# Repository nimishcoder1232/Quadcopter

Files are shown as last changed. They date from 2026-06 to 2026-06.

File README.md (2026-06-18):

# DIY-Quad-Copter
I want to make a drone that is completely autonomous, with my own flight computer. I will not use any drone control software; rather, I will make it all. The code from scratch, to learn as much as I can.

For the outpost submission, I will request S teir, rather than A teir. My reasons are following:

1. Custom Flight Control Software

The drone's flight software is entirely custom and has been developed from scratch by me. Unlike drones that rely on commercial off-the-shelf (COTS) flight control software such as Betaflight or similar systems, this project requires the development of a complete flight control stack, including sensor fusion, state estimation, and stabilization algorithms.

Developing this software has required extensive research into control systems, quaternion-based orientation estimation, complementary filters, and drone dynamics. Additionally, I anticipate multiple iterations and redesigns of the software before achieving reliable flight performance, making this a highly ambitious component of the project.

2. GPS-Based Autonomous Navigation

This drone is designed to support GPS navigation capabilities. The current codebase already contains foundational GPS-related functionality, and future development will include point-to-point autonomous navigation.

Implementing autonomous navigation significantly increases the complexity of the system, as it requires integration of GPS data with the flight controller, position estimation, waypoint tracking, and autonomous control logic.

3. Custom Ground Control System

In the PCB folder, you can see that I designed my own drone control board, rather than a COTS solution. 

CAD Screenshot: 


PCB Schematic: 


PCB Routing: 


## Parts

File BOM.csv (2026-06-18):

Item Name | Qty | Price (total) (USD) | Item link | Notes
Brushless motors and ESC | 1 | $53.00 | https://www.amazon.com/gp/product/B0BW5H7Y8Q/ref | This is an example part! Add things to note here.
Batteries | 1 | $53.00 | https://www.amazon.com/gp/product/B09CTSD386/ref
Cost to hackclub | 106$ | (Dont forget tax :D)
Stuff I will provide myself:
GNSS GPS | 1 |  | https://www.amazon.com/hiBCTR-GY-NEO6MV2-Controller-Ceramic-Antenna/dp/B0FWC1J7J4/ref
Fillament | 1 |  | (Varrious Sources)
ESP 32 s3 | 1 |  | https://www.amazon.com/Development-ESP32-S3-DevKit-Bluetooth-Internet-ESP32-S3-1-N16R8/dp/B0GVQJ5TST/ref
BMI270 | 1 |  | https://www.sparkfun.com/sparkfun-6dof-imu-breakout-bmi270-qwiic.html
LM317 | 1 |  | https://www.amazon.com/ALLECIN-LM317T-Voltage-Regulator-Adjustable/dp/B0CBLN2X7H/ref
Resistors | 1 |  | https://www.amazon.com/ONJYHK-100Values-Resistor-Resistors-Assortment/dp/B0GJYDKNPC/ref=
Capasitors | 1 |  | https://www.amazon.com/ALLECIN-Electrolytic-Capacitor-Assortment-Kit/dp/B0C1VBXCQM/ref

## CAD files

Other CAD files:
CAD/dronefinalcad.step

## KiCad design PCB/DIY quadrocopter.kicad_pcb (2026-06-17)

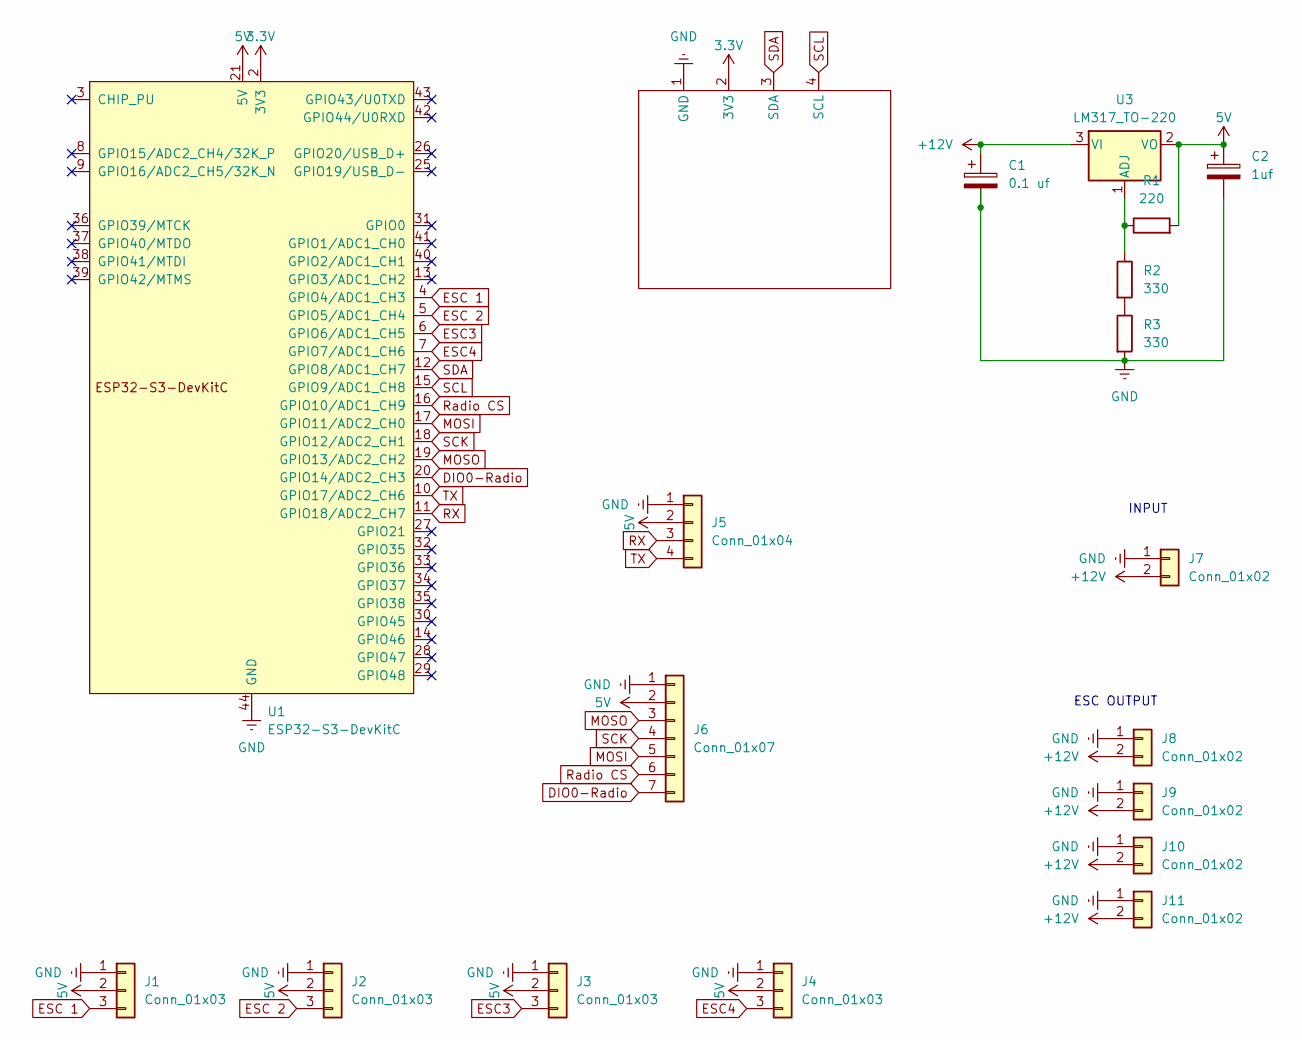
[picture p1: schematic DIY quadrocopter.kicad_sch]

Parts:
C1: 0.1 uf; CP_Radial_D5.0mm_P2.50mm
C2: 1uf; CP_Radial_D5.0mm_P2.50mm
J1, J2, J3, J4: Conn_01x03; PinHeader_1x03_P2.54mm_Vertical
J5: Conn_01x04; PinHeader_1x04_P2.54mm_Vertical
J6: Conn_01x07; PinHeader_1x07_P2.54mm_Vertical
J7, J8, J9, J10, J11: Conn_01x02; SolderWire-2sqmm_1x02_P7.8mm_D2mm_OD3.9mm
R1: 220; R_Axial_DIN0309_L9.0mm_D3.2mm_P12.70mm_Horizontal
R2, R3: 330; R_Axial_DIN0309_L9.0mm_D3.2mm_P12.70mm_Horizontal
U1: ESP32-S3-DevKitC; ESPP 32
U2: BMI270; PinHeader_1x06_P2.54mm_Vertical
U3: LM317_TO-220; TO-220-3_Vertical

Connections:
3.3V: U1.1 (3V3), U1.2 (3V3), U2.2 (3V3)
5V: C2.1, J1.2, J2.2, J3.2, J4.2, J5.2, J6.2, R1.2, U1.21 (5V), U3.2 (VO)
+12V: C1.1, J7.2, J8.2, J9.2, J10.2, J11.2, U3.3 (VI)
DIO0-Radio: J6.7, U1.20 (GPIO14/ADC2_CH3)
ESC3: J3.3, U1.6 (GPIO6/ADC1_CH5)
ESC4: J4.3, U1.7 (GPIO7/ADC1_CH6)
ESC 1: J1.3, U1.4 (GPIO4/ADC1_CH3)
ESC 2: J2.3, U1.5 (GPIO5/ADC1_CH4)
GND: C1.2, C2.2, J1.1, J2.1, J3.1, J4.1, J5.1, J6.1, J7.1, J8.1, J9.1, J10.1, J11.1, R3.2, U1.22 (GND), U1.23 (GND), U1.24 (GND), U1.44 (GND), U2.1 (GND)
MOSI: J6.5, U1.17 (GPIO11/ADC2_CH0)
MOSO: J6.3, U1.19 (GPIO13/ADC2_CH2)
unnamed: R2.2, R3.1
unnamed: R1.1, R2.1, U3.1 (ADJ)
RX: J5.3, U1.11 (GPIO18/ADC2_CH7)
Radio CS: J6.6, U1.16 (GPIO10/ADC1_CH9)
SCK: J6.4, U1.18 (GPIO12/ADC2_CH1)
SCL: U1.15 (GPIO9/ADC1_CH8), U2.4 (SCL)
SDA: U1.12 (GPIO8/ADC1_CH7), U2.3 (SDA)
TX: J5.4, U1.10 (GPIO17/ADC2_CH6)

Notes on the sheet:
INPUT
ESC OUTPUT

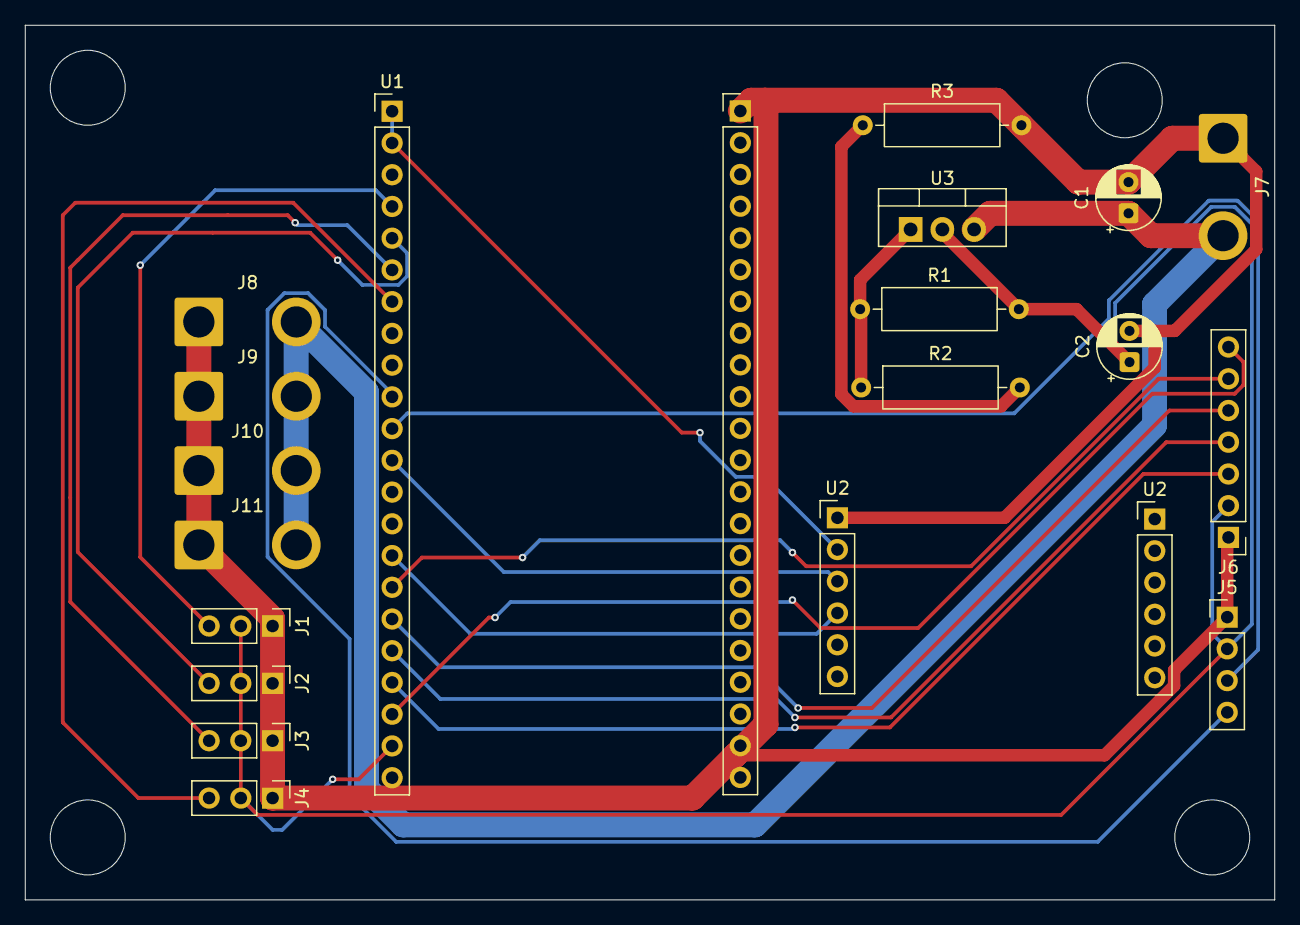
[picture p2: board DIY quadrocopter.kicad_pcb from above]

Board: 2 copper layers, 100.0 x 70.0 mm, 20 parts (0 on the bottom side), 19 nets.

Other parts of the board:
U2#2: BMI270; PinHeader_1x06_P2.54mm_Vertical

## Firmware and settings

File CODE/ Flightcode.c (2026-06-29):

#include <Arduino.h>
#include <esp_now.h>
#include <WiFi.h>
#include <Wire.h>
#include <SparkFun_BMI270_Arduino_Library.h>


BMI270 imu;

typedef struct {
  float throttle;
  float x;
  float y;
  float z;
  bool  arm;
} ControlPacket;

ControlPacket input;
volatile unsigned long lastPacketTime = 0;

// ── Config ────────────────────────────────────────────────────────────────
const int ESC_PINS[]  = {42, 4, 5, 2};
const int NUM_ESCS    = 4;
const int PWM_FREQ    = 50;
const int PWM_BITS    = 12;
const int PWM_MIN_US  = 1000;
const int PWM_MAX_US  = 2000;

// ── Helpers ───────────────────────────────────────────────────────────────
uint32_t usToDuty(int pulseUs) {
    return (uint32_t)(pulseUs * 4095.0f / 20000.0f);
}

void setESC(int pin, int pulseUs) {
    pulseUs = constrain(pulseUs, PWM_MIN_US, PWM_MAX_US);
    ledcWrite(pin, usToDuty(pulseUs));
}




// ============== ORIENTATION (QUATERNION) ==============
float q0 = 1, q1 = 0, q2 = 0, q3 = 0;
float gyroBiasX = 0, gyroBiasY = 0, gyroBiasZ = 0;
float angleX = 0, angleY = 0, angleZ = 0;

const float DEG2RAD = 0.017453292f;
const float RAD2DEG = 57.295780f;

float mahonyKp = 2.0f;
float mahonyKi = 0.02f;
float ixCorr = 0, iyCorr = 0, izCorr = 0;

void updateOrientation(float dt) {
  imu.getSensorData();
  float ax = imu.data.accelX;
  float ay = imu.data.accelY;
  float az = imu.data.accelZ;
  float gx = (imu.data.gyroX - gyroBiasX) * DEG2RAD;
  float gy = (imu.data.gyroY - gyroBiasY) * DEG2RAD;
  float gz = (imu.data.gyroZ - gyroBiasZ) * DEG2RAD;

  float accelNorm = sqrtf(ax*ax + ay*ay + az*az);
  if (accelNorm > 0.0001f) {
    ax /= accelNorm; ay /= accelNorm; az /= accelNorm;

    float vx = 2.0f * (q1*q3 - q0*q2);
    float vy = 2.0f * (q0*q1 + q2*q3);
    float vz = q0*q0 - q1*q1 - q2*q2 + q3*q3;

    float ex = ay*vz - az*vy;
    float ey = az*vx - ax*vz;
    float ez = ax*vy - ay*vx;

    float trust = 1.0f - fabsf(accelNorm - 1.0f);
    trust = constrain(trust, 0.0f, 1.0f);

    ixCorr += mahonyKi * ex * dt * trust;
    iyCorr += mahonyKi * ey * dt * trust;
    izCorr += mahonyKi * ez * dt * trust;

    gx += mahonyKp * ex * trust + ixCorr;
    gy += mahonyKp * ey * trust + iyCorr;
    gz += mahonyKp * ez * trust + izCorr;
  }

  float qDot0 = 0.5f * (-q1*gx - q2*gy - q3*gz);
  float qDot1 = 0.5f * ( q0*gx + q2*gz - q3*gy);
  float qDot2 = 0.5f * ( q0*gy - q1*gz + q3*gx);
  float qDot3 = 0.5f * ( q0*gz + q1*gy - q2*gx);

  q0 += qDot0 * dt;
  q1 += qDot1 * dt;
  q2 += qDot2 * dt;
  q3 += qDot3 * dt;

  float qNorm = sqrtf(q0*q0 + q1*q1 + q2*q2 + q3*q3);
  q0 /= qNorm; q1 /= qNorm; q2 /= qNorm; q3 /= qNorm;

  angleX = atan2f(2.0f*(q0*q1 + q2*q3), 1.0f - 2.0f*(q1*q1 + q2*q2)) * RAD2DEG;
  angleY = asinf(constrain(2.0f*(q0*q2 - q1*q3), -1.0f, 1.0f)) * RAD2DEG;
  angleZ = atan2f(2.0f*(q0*q3 + q1*q2), 1.0f - 2.0f*(q2*q2 + q3*q3)) * RAD2DEG;
}

// ============== PID ==============
float KpX = 0.7, KiX = 0.005, KdX = 0.06;
float KpY = 0.7, KiY = 0.005, KdY = 0.06;
float KpZ = 0.3;

float pidIntegX = 0, pidIntegY = 0;
float lastErrX = 0, lastErrY = 0;
float dFiltX = 0, dFiltY = 0;
const float D_FILTER_ALPHA = 0.3f;

float pid(float setpoint, float measured, float &integ, float &lastErr, float &dFilt,
           float kp, float ki, float kd, float dt) {
  float err = setpoint - measured;
  integ += err * dt;
  integ = constrain(integ, -50.0f, 50.0f);
  float dRaw = (err - lastErr) / dt;
  dFilt += D_FILTER_ALPHA * (dRaw - dFilt);
  lastErr = err;
  return kp*err + ki*integ + kd*dFilt;
}

// ============== ESP-NOW ==============
void onReceive(const esp_now_recv_info_t *info, const uint8_t *data, int len) {
  if (len != sizeof(ControlPacket)) return;
  memcpy(&input, data, sizeof(input));
  lastPacketTime = millis();
}

// ============== SETUP ==============
unsigned long lastTime;


void setup() {
    Serial.begin(115200);

    for (int i = 0; i < NUM_ESCS; i++) {
        ledcAttach(ESC_PINS[i], PWM_FREQ, PWM_BITS);
        ledcWrite(ESC_PINS[i], usToDuty(PWM_MIN_US));
    }

    Serial.println("Arming – keep props off!");
    delay(3000);
    Serial.println("Armed.");

    Wire.begin();

  if (imu.beginI2C() != BMI2_OK) {
    Serial.println("BMI270 not found - check wiring");
    while (1) delay(10);
  }
  Serial.println("Calibrating gyro - keep the frame still...");
  long n = 0;
  double sumX = 0, sumY = 0, sumZ = 0;
  unsigned long calStart = millis();
  while (millis() - calStart < 1500) {
    imu.getSensorData();
    sumX += imu.data.gyroX;
    sumY += imu.data.gyroY;
    sumZ += imu.data.gyroZ;
    n++;
    delay(2);
  }
  gyroBiasX = sumX / n;
  gyroBiasY = sumY / n;
  gyroBiasZ = sumZ / n;
  Serial.println("Gyro calibration done.");

  WiFi.mode(WIFI_STA);

  Serial.println("Setting WiFi mode...");
  if (esp_now_init() != ESP_OK) {
    Serial.println("ESP-NOW init failed");
    while (1) delay(10);
  }

  Serial.println("Initializing ESP-NOW...");


  esp_now_register_recv_cb(onReceive);

  Serial.println("Registering callback...");

  Serial.print("This board's MAC (give it to the transmitter sketch): ");
  Serial.println(WiFi.macAddress());

  lastTime = micros();
  lastPacketTime = millis();
    
}

// ── Loop ──────────────────────────────────────────────────────────────────
void loop() {
  unsigned long now = micros();
  float dt = (now - lastTime) * 1e-6f;
  lastTime = now;
  if (dt <= 0 || dt > 0.5f) dt = 0.002f;

  updateOrientation(dt);

/*
  if (millis() - lastPacketTime > 100) {
    input.arm = false;
  }
*/
  if (!input.arm) {
    setESC(ESC_PINS[0], 1000);
    setESC(ESC_PINS[1], 1000);
    setESC(ESC_PINS[2], 1000);
    setESC(ESC_PINS[3], 1000);
    
    pidIntegX = 0; pidIntegY = 0;
    Serial.println("ABORTED");
    return;
  }

  float outX = -(pid(-input.x, angleY, pidIntegX, lastErrX, dFiltX, KpX, KiX, KdX, dt));
  float outY = -(pid(input.y, angleX, pidIntegY, lastErrY, dFiltY, KpY, KiY, KdY, dt));
  float outZ = KpZ * (input.z - (imu.data.gyroZ - gyroBiasZ));


  float t = input.throttle * 100;

  // quad-X mixing
  float m1 = t + outY + outX - outZ;
  float m2 = t + outY - outX + outZ;
  float m3 = t - outY + outX + outZ;
  float m4 = t - outY - outX - outZ;

  int us1 = constrain(1000 + 10 * m1, 1000, 2000);
  int us2 = constrain(1000 + 10 * m2, 1000, 2000);
  int us3 = constrain(1000 + 10 * m3, 1000, 2000);
  int us4 = constrain(1000 + 10 * m4, 1000, 2000);  
  
  
  setESC(ESC_PINS[0], us1);
  setESC(ESC_PINS[1], us2);
  setESC(ESC_PINS[2], us3);
  setESC(ESC_PINS[3], us4);
}

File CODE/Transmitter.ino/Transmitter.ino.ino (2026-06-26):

#include <Arduino.h>
#include <WiFi.h>
#include <esp_now.h>

typedef struct {
  float throttle;
  float x;
  float y;
  float z;
  bool arm;
} ControlPacket;

ControlPacket packet;

uint8_t receiverMac[] = {0x30, 0xED, 0xA0, 0xA4, 0xD8, 0x38};

esp_now_peer_info_t peer;

float lx = 0;
float ly = 0;
float rx = 0;
float ry = 0;

float throttle = 0.0f;
bool armed = true;

unsigned long lastTime;

void setup() {
  Serial.begin(9600);

  WiFi.mode(WIFI_STA);

  if (esp_now_init() != ESP_OK) {
    Serial.println("ESP-NOW init failed");
    while (1);
  }

  memcpy(peer.peer_addr, receiverMac, 6);
  peer.channel = 0;
  peer.encrypt = false;

  if (esp_now_add_peer(&peer) != ESP_OK) {
    Serial.println("Failed to add peer");
    while (1);
  }

  Serial.println("Transmitter Ready");
  lastTime = millis();
}

void loop() {
  float dt = (millis() - lastTime) / 1000.0f;
  lastTime = millis();

  if (Serial.available()) {
    String line = Serial.readStringUntil('\n');
    line.trim();

    // Abort command from Python
    if (line == "ABORT") {
      Serial.println("ABORT RECEIVED");

      armed = false;
      throttle = 0.0f;

      packet.throttle = 0.0f;
      packet.x = 0.0f;
      packet.y = 0.0f;
      packet.z = 0.0f;
      packet.arm = false;

      esp_now_send(receiverMac, (uint8_t *)&packet, sizeof(packet));
      return;
    }

    // Parse joystick values: lx,ly,rx,ry
    if (sscanf(line.c_str(), "%f,%f,%f,%f", &lx, &ly, &rx, &ry) == 4) {

      // Throttle controlled by right stick Y
      if (armed && fabs(ly) > 0.1f) {
        throttle += ly * dt;
      }

      throttle = constrain(throttle, 0.0f, 0.8f);

      packet.throttle = throttle;
      packet.x = rx * 20.0f;      // X angle target (deg)
      packet.y = ry * 20.0f;      // Y angle target (deg)
      packet.z = lx * 60.0f;     // Z rate target (deg/s)
      packet.arm = armed;

      esp_now_send(receiverMac, (uint8_t *)&packet, sizeof(packet));
    }
  }
  delay(20);
}

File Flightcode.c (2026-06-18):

#include <Wifi.h>
#include <esp_now.h>
#include <Wire.h>
#include <SparkFun_BMI270_Arduino_Library.h>

BMI270 imu;

// Transmitter Pairing 

uint8_t transmitter_mac[6] = {0x24, 0x6F, 0x28, 0x87, 0x12, 0x35};

typedef struct {
    float throttle;
    float x;
    float y; 
    float z;
    bool arm; 

}controlcommand;

controlcommand input;

volatile unsigned long last Packet Time = 0;

// ESC HANDLING 
const int ESC_PIN[4] = {25, 26, 27, 14};
const int PWM_FREQUENCY = 400;
const int PWM_RESOLUTION = 16;
const long PWM_MAX_DUTY = (1l << PWM_RESOLUTION) - 1;

void writeESC(int idx, float v){
    v = constrain(v, 0.0f, 1.0f);
    long duty = (long)us * PWM_frequency * PWM_MAX_DUTY / 1000000.0L;
    ledcWrite(ESC_PIN[idx],duty);
}

void setAllESC(float v) {
    for (int i = 0; i < 4; i++) writeESC(i, v);
}
  
void armESCs() {
    setAllESC(0.0); delay(2000);
    setAllESC(0.10); delay(2000);
    setAllESC(0.0); delay(2000);
}

float q0 =1, q1 = 0, q2 = 0, q3 = 0;
float gyroBiasX = 0, gyroBiasY = 0, gyroBiasZ = 0;

float angleX = 0, angleY = 0, angleZ = 0;

const float DEG2RAD = 0.017453292f;

const float RAD2DEG = 57.2957795131f;

float mahonyKp = 2.0f; // for the complementary filter that fuses the gyro and accelerometer data we need the software to know how much to trust the gyro and how much to trust the accelerometer
float mahonyKi = 0.02f; // Cancels out residual bias of gyro using the acelerometer 

float ixCorr = 0, iyCorr = 0, izCorr =0; 

void updateOrientation(){
    imu.getSensorData();
    float ax =  IMU.getAccelX();                       // get sensor outputs 
    float ay =  IMU.getAccelY();
    float az =  IMU.getAccelZ();
    float gx =  (IMU.getGyroX() - gyroBiasX) * DEG2RAD;
    float gy =  (IMU.getGyroY() - gyroBiasY) * DEG2RAD;
    float gz =  (IMU.getGyroZ() - gyroBiasZ) * DEG2RAD;

    float acelNorm = sqrtf(ax*ax + ay*ay + az*az);

    if (acelNorm > 0.0001f){
        ax /= acelNorm; ay /= acelNorm; az /= acelNorm;

        float vx = 2.0f * (q1*q3 - q0*q2);  // define filter down points 
        float vy = 2.0f * (q0*q1 + q2*q3);
        float vz = q0*q0 - q1*q1 - q2*q2 + q3*q3;

        float ex = ay*vz - az&vy;  // gravity missmatch
        float ey = az*vx - ax*vz;
        float ez = ax*vy - ay*vx; 

        float trust = 1.0f - fabsf(acelNorm - 1.0f);
        trust = constrain(trust, 0.0f, 1.0f);

        ixCorr += mahonyKi * ex * dt * trust; 
        iyCorr += mahonyKi * ey * dt * trust;
        izCorr += mahonyKi * ex * dt * trust;

        gx += mahonyKp * ex * trust + ixCorr; 
        gy += mahonyKp * ey * trust + iyCorr; 
        gz += mahonyKp * ez * trust + izCorr; 
    }

    float qDot0 = 0.5f * (-q1*gx - q2*gy - q3*gz);
    float qDot1 = 0.5f * ( q0*gx + q2*gz - q3*gy);
    float qDot2 = 0.5f * ( q0*gy - q1*gz + q3*gx);
    float qdot3 = 0.5f * ( q0*gz + q1*gy - q2*gx);

    q0 += qDot0 * dt;
    q1 += qDot1 * dt;
    q2 += qDot2 * dt; 
    q3 += qdot3 * dt;

    float qNorm = sqrtf(q0*q0 + q1*q1 + q2*q2+ q3*q3);

    q0 /= qNorm; q1 /= qNorm; q2 /= qNorm; q3 /= qNorm;

    angleX = atan2f(2.0f*(q0*q1 + q2*q3), 1.0f - 2.0f*(q1*q1 + q2*q2)) * RAD2DEG;
    angleY = asinf(constrain(2.0f*(q0*q2 - q1*q3), -1.0f, 1.0f)) * RAD2DEG;
    angleZ = atan2f(2.0f*(q0*q3 + q1*q2), 1.0f - 2.0f*(q2*q2 + q3*q3)) * RAD2DEG;
}

float ptermx = 0.02, itermx = 0.0, dtermX = 0.005; 
float ptermy = 0.02, itermy = 0.0, dtermy = 0.005; 

float Ztermp = 0.01;

float pidintegx = 0, pidintegy = 0;
float lasterrorx = 0, lasterrory = 0; 
float dFiltX = 0, dFiltY = 0;
const float D_filter = 0.2f;

float pid(float setpoint, float measured, float &integ, float &lastErr, float &dFilt, float kp, float ki, float kd, float dt){
    float err = setpoint - measured;
    integ += err * dt;
    integ = constrain(integ, -0.5f, 0.5f);
    float dRaw = (err - lastErr) / dt;
    dFilt += D_filter * (dRaw-dFilt);
    lastErr = err;

    return kp * err + ki*integ + kd*dFilt; 
}

void onRecieval(const esp_now_recv_info_t *info, const uint8_t *data, int len){
    if (memcmp(info->src_addr, transmitter_mac, 6) != 0) {
        return;
    }

    if (len != sizeof(controlcommand)){
        return
    }

    memcpy(&input, data, sizeof(input));

    lastPacketTime = millis();
}

unsigned long lastTime;

void setup(){
    Serial.begin(115200);
    Wire.begin();

    if (imu.beginI2C() != BMI2_OK){
        Serial.println("BMI 270 NOT FOUND D:");
        while (1) delay(10);
    }

    Serial.println("Calibrating GYRO stay still plz");

    long n = 0;
    
    double sumX = 0, sumY = 0, sumZ = 0;

    while (millis() - calStart < 1500) {
        imu.getSensorData();
        sumX += imu.data.gyroX;
        sumY += imu.data.gyroY;
        sumZ += imu.data.gyroZ;
        n++;
        delay(2);
    }
    BiasX = sumX / n;
    BiasY = sumY / n;
    BiasZ = sumZ / n;

    Serial.println("sensor happy :D ");

    Wifi.mode(WIFI_STA);
    if (esp_now_init() != ESP_OK) {
        Serial.println("ESP-NOW is screwed");
        while (1) delay(10);
    }
    esp_now_register_recv_cb(onReceive);

    for (int i = 0; i < 4; i++) ledcAttach(ESC_PIN[i], PWM_FREQ, PWM_RES);

    armESCs();

    Serial.print("Flight comptuer mac adress");
    Serial.println(WiFi.macAddress());

    lastTime = micros();
    lastPacketTime = millis();
}

void loop{
    unsigned long now = micros();
    float dt = (now - lastTime)* 1e-6f;

    lastTime = now;

    if (dt <=0 || dt>0.5f) dt = 0.002f;

    updateOrientation(dt);

    if (millis() - lastPacketTime > 100){
        input.arm = false;
    }

    if (!input.arm){
        setAllESC(0.0);
        pidintegx = 0; pidintegy = 0;
    }

    float outX = pid(input.x, angleX, pidintegx,lasterrorx, dFiltX,ptermx,itermx,dtermx);
    float outy = pid(input.y, angleY, pidintegy,lasterrory, dFilty,ptermy,itermy,dtermy);
    float outZ =Ztermp * (input.z - angleZ);

    float t = input.throttle;

    float m1 = t + outY + outX - outZ;
    float m2 = t + outY - outX + outZ;
    float m3 = t - outY + outX + outZ;
    float m4 = t - outY - outX - outZ;
  
    writeESC(0, m1);
    writeESC(1, m2);
    writeESC(2, m3);
    writeESC(3, m4);


}

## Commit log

2026-06-17 Rename DIY quadrocopter.kicad_pcb to PCB/DIY quadrocopter.kicad_pcb
    [DIY quadrocopter.kicad_pcb]
2026-06-17 Rename DIY quadrocopter.kicad_prl to PCB/DIY quadrocopter.kicad_prl
2026-06-17 Rename DIY quadrocopter.kicad_pro to PCB/DIY quadrocopter.kicad_pro
2026-06-17 Rename DIY quadrocopter.kicad_sch to PCB/DIY quadrocopter.kicad_sch
    [DIY quadrocopter.kicad_sch]
2026-06-18 Enhance README with project details and images
    Expanded the README to detail custom flight control software, GPS navigation, and ground control system.
2026-06-18 Rename Drone BOMB - Sheet1.csv to BOM.csv
    [BOM.csv]
